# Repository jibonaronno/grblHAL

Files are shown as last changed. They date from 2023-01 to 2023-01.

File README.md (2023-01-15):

# grblHAL
STM32F401 GRBL Controller over BlackPill board.

Schematic and layout are completed. Screw Terminal Connectors and optos are aligned. Added 4 TMC2208.<br>

### Inspired from <a href="https://github.com/avizienis/Minimal-Black-Pill--STM32F4xx-BOB-for-grblHAL">Minimal-Black-Pill--STM32F4xx-BOB-for-grblHAL</a><br>
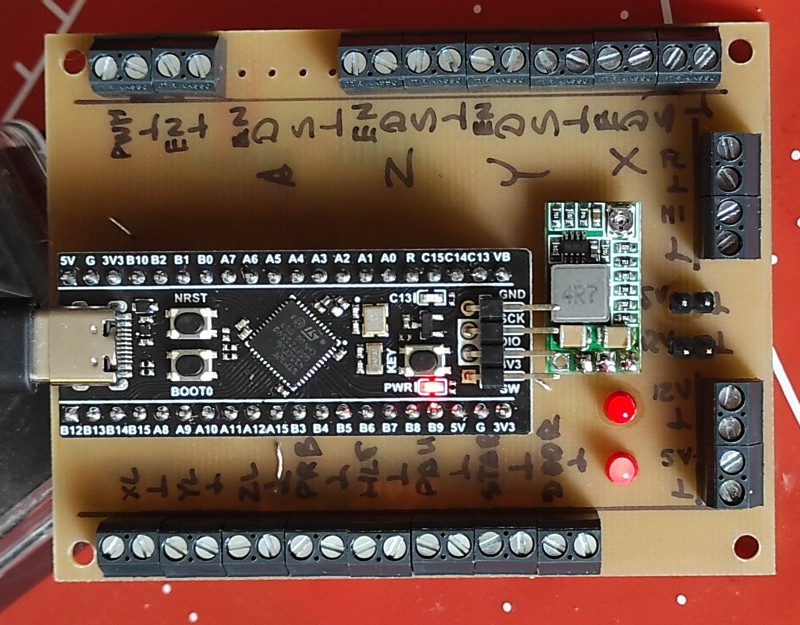
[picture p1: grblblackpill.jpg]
Image Not Found
<br>

### Our Kicad design below.<br/>
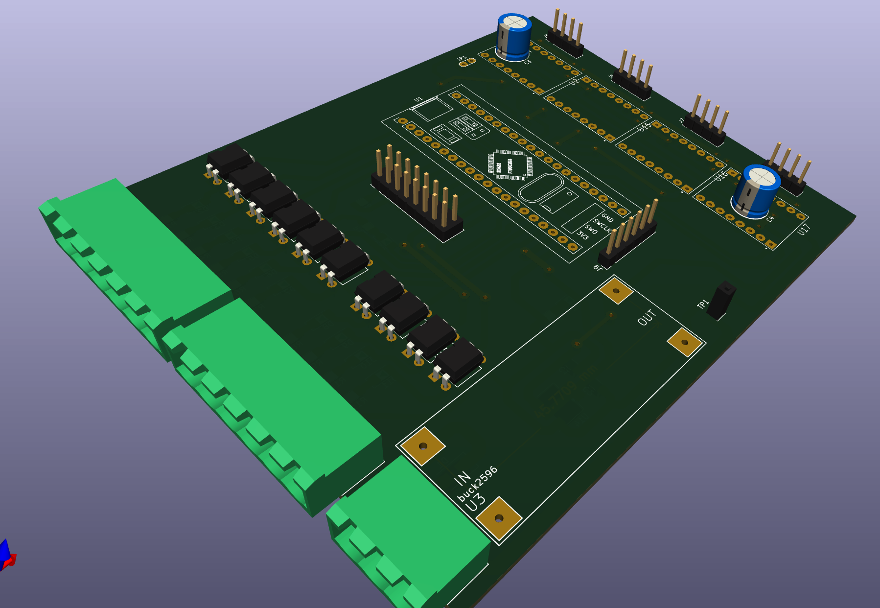
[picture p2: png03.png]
<br>
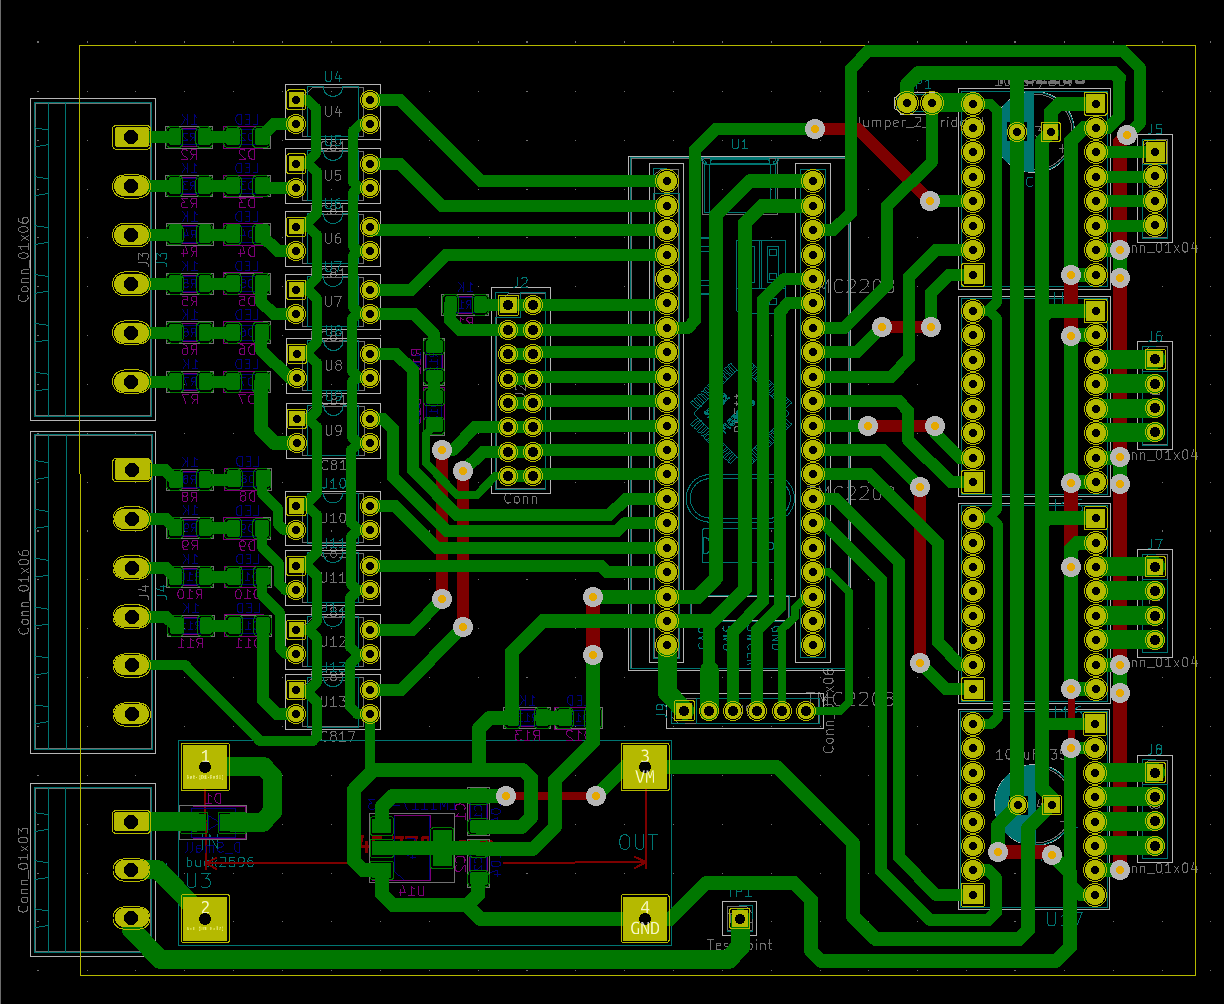
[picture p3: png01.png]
<br>
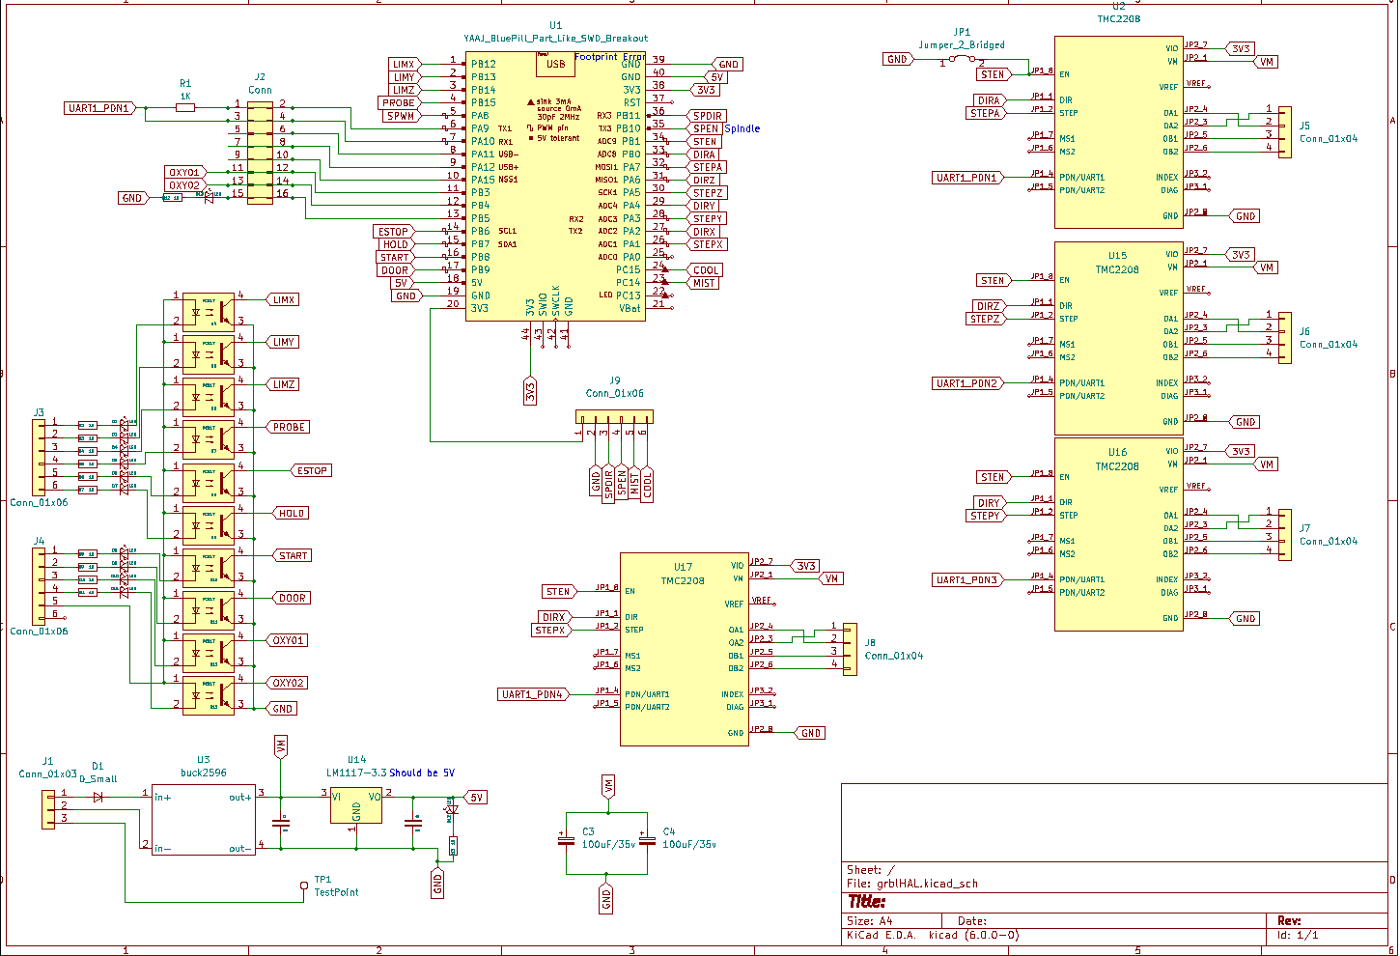
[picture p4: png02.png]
<br>

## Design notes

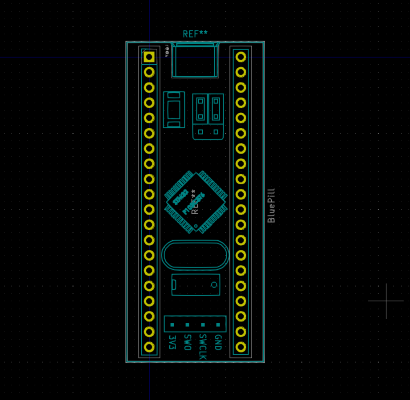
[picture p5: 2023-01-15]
images/YAAJ_BluePill_1_Footprint.png

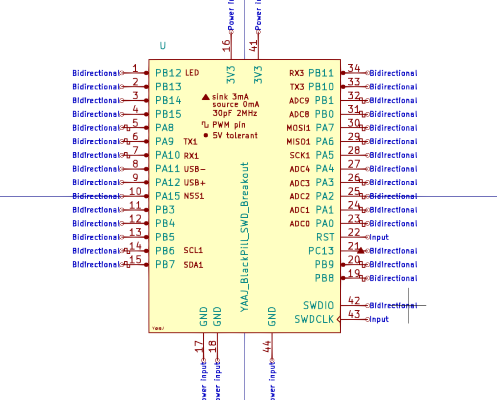
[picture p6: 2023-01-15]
images/YAAJ_BlackPill_SWD_Breakout_Sym.png

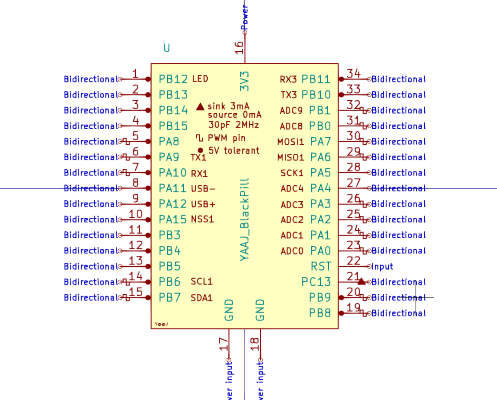
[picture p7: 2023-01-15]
images/YAAJ_BlackPill_Sym.png

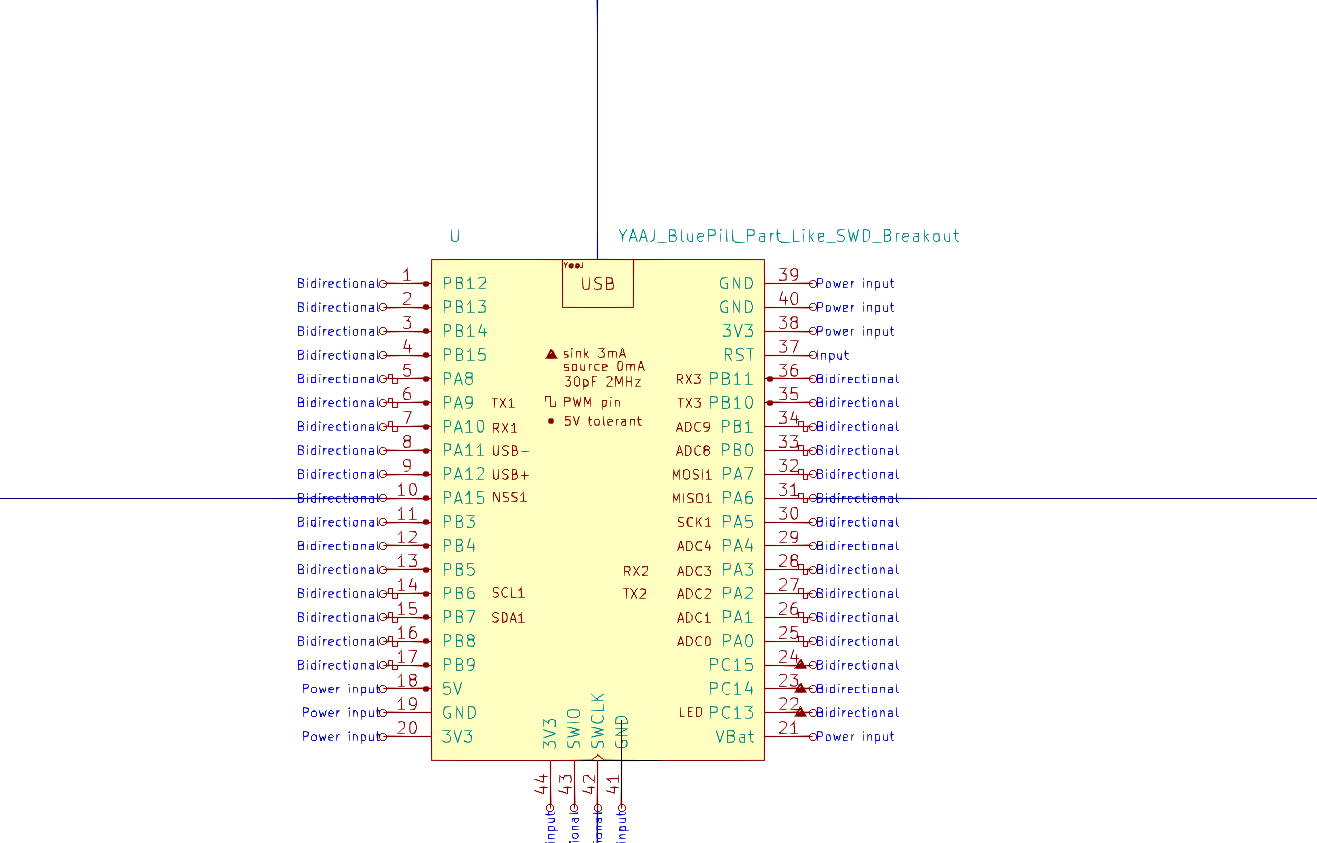
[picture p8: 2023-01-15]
images/YAAJ_BluePill_Part_Like_SWD_Breakout.png

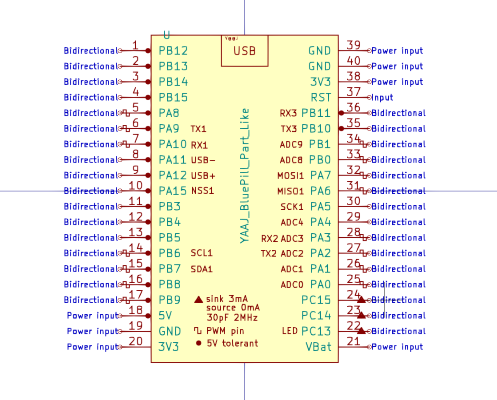
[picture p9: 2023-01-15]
images/YAAJ_BluePill_Part_Like_Sym.png

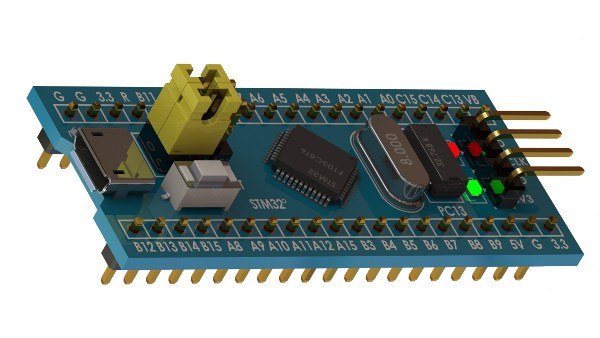
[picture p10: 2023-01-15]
images/BluePill.JPG

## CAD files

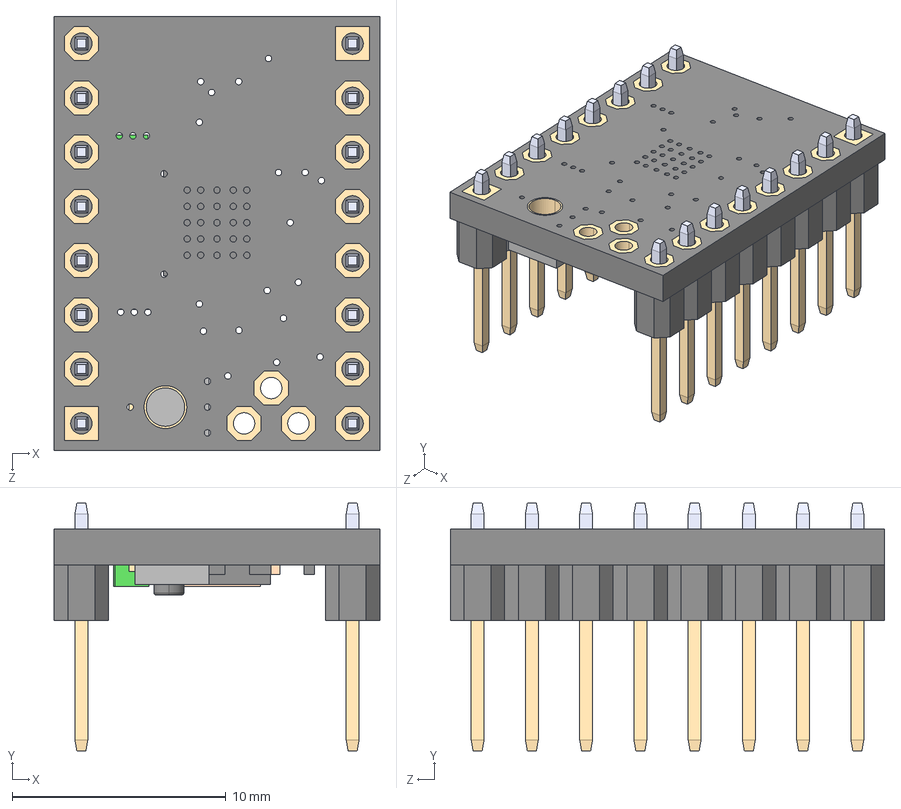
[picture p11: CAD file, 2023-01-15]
TMC2208_SILENTSTEPSTICK/TMC2208_SILENTSTEPSTICK.step
15.2 x 11.6 x 20.3 mm

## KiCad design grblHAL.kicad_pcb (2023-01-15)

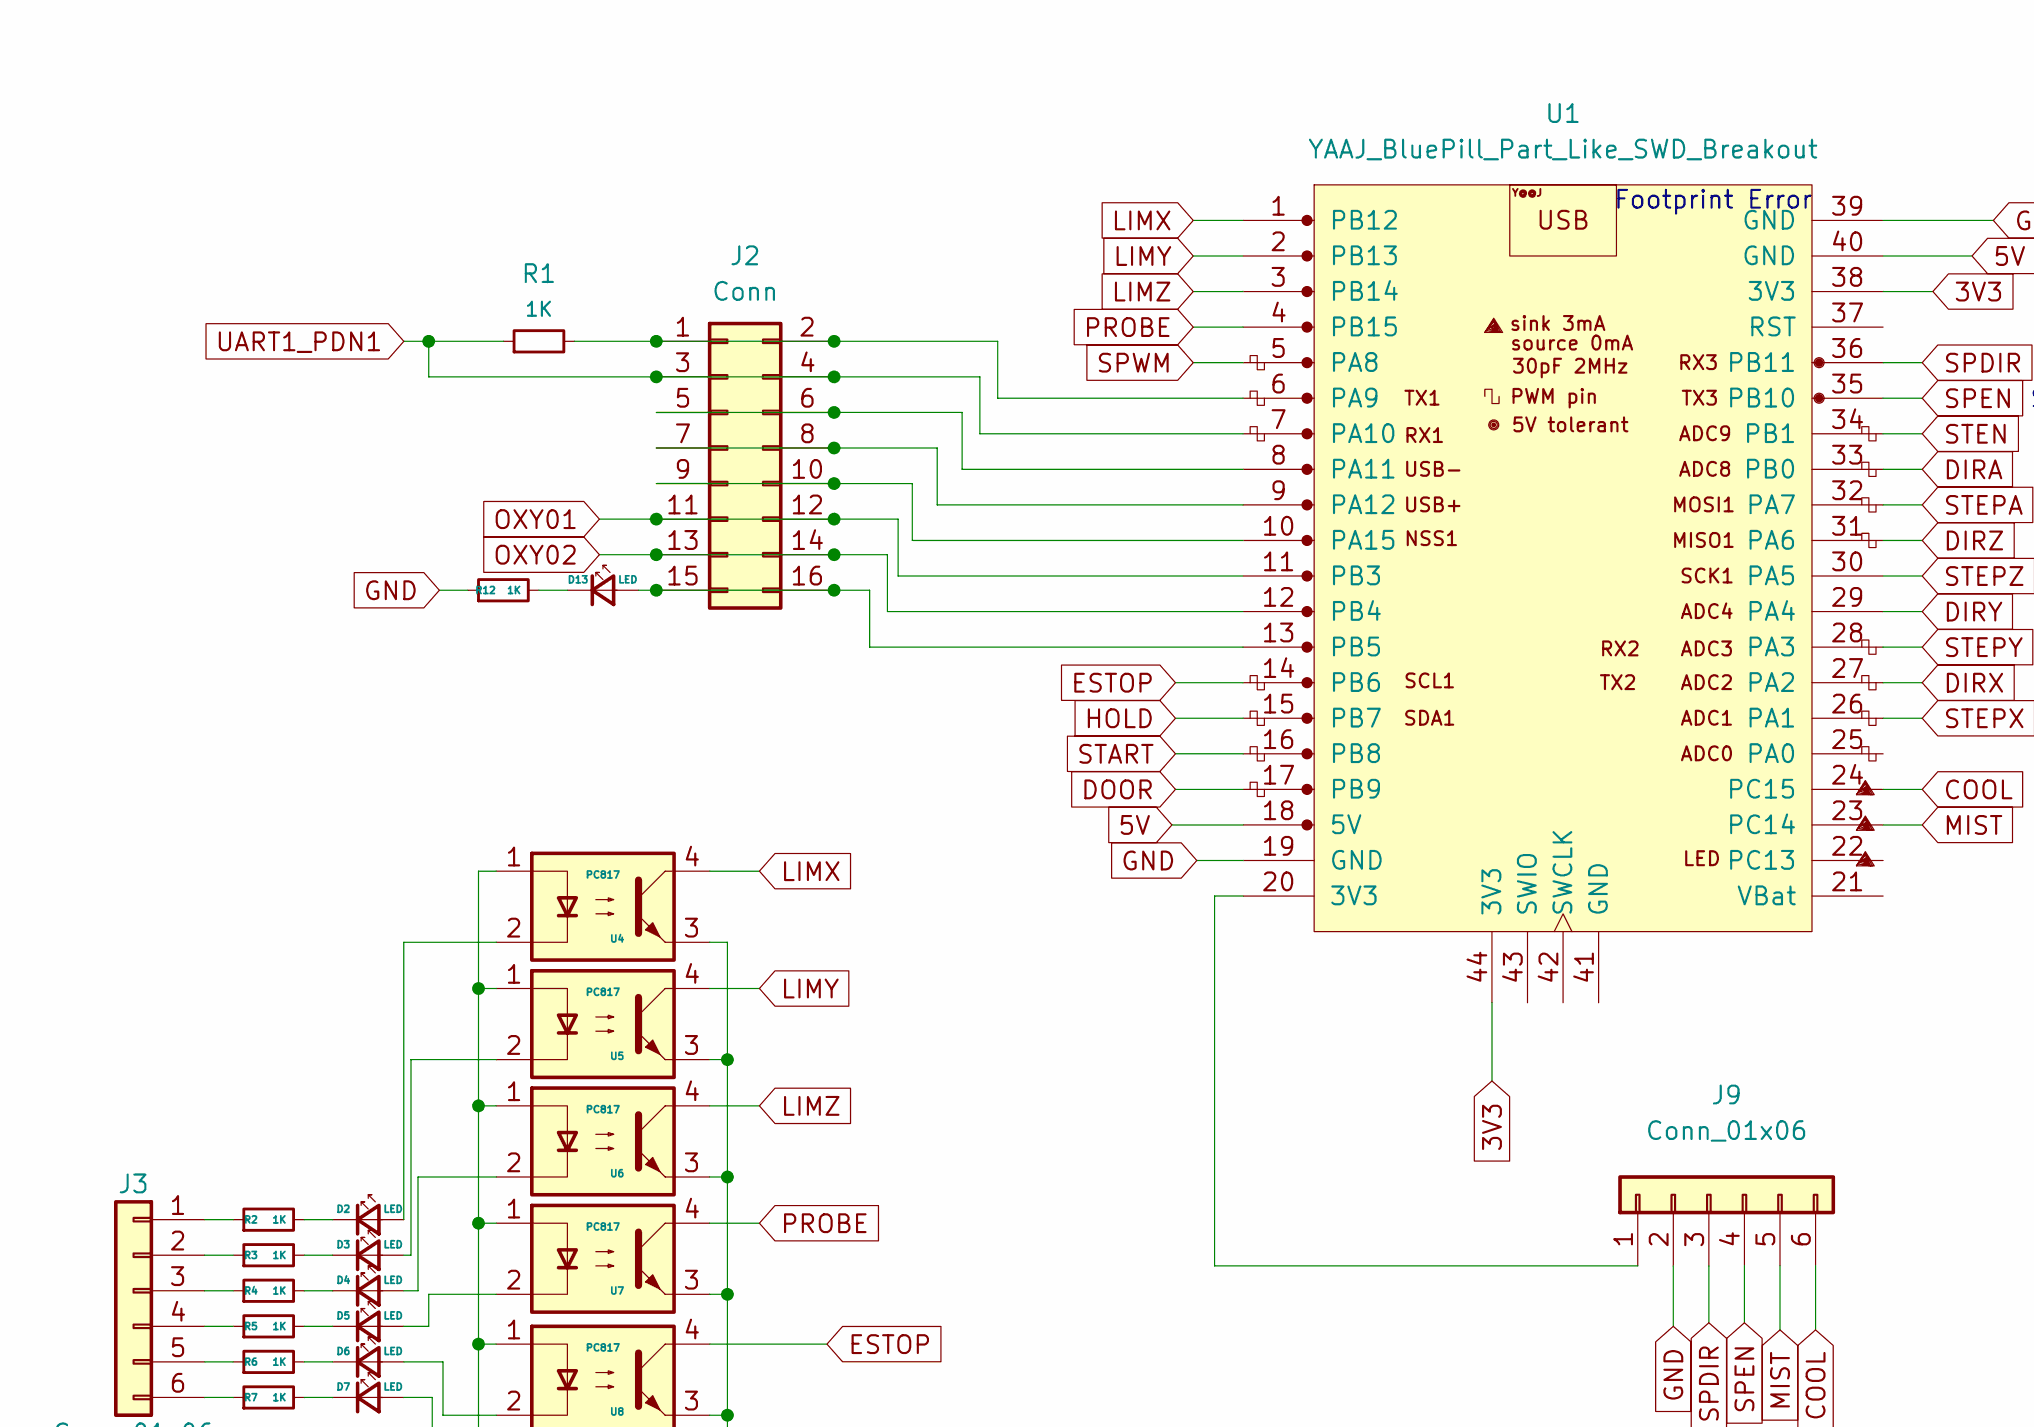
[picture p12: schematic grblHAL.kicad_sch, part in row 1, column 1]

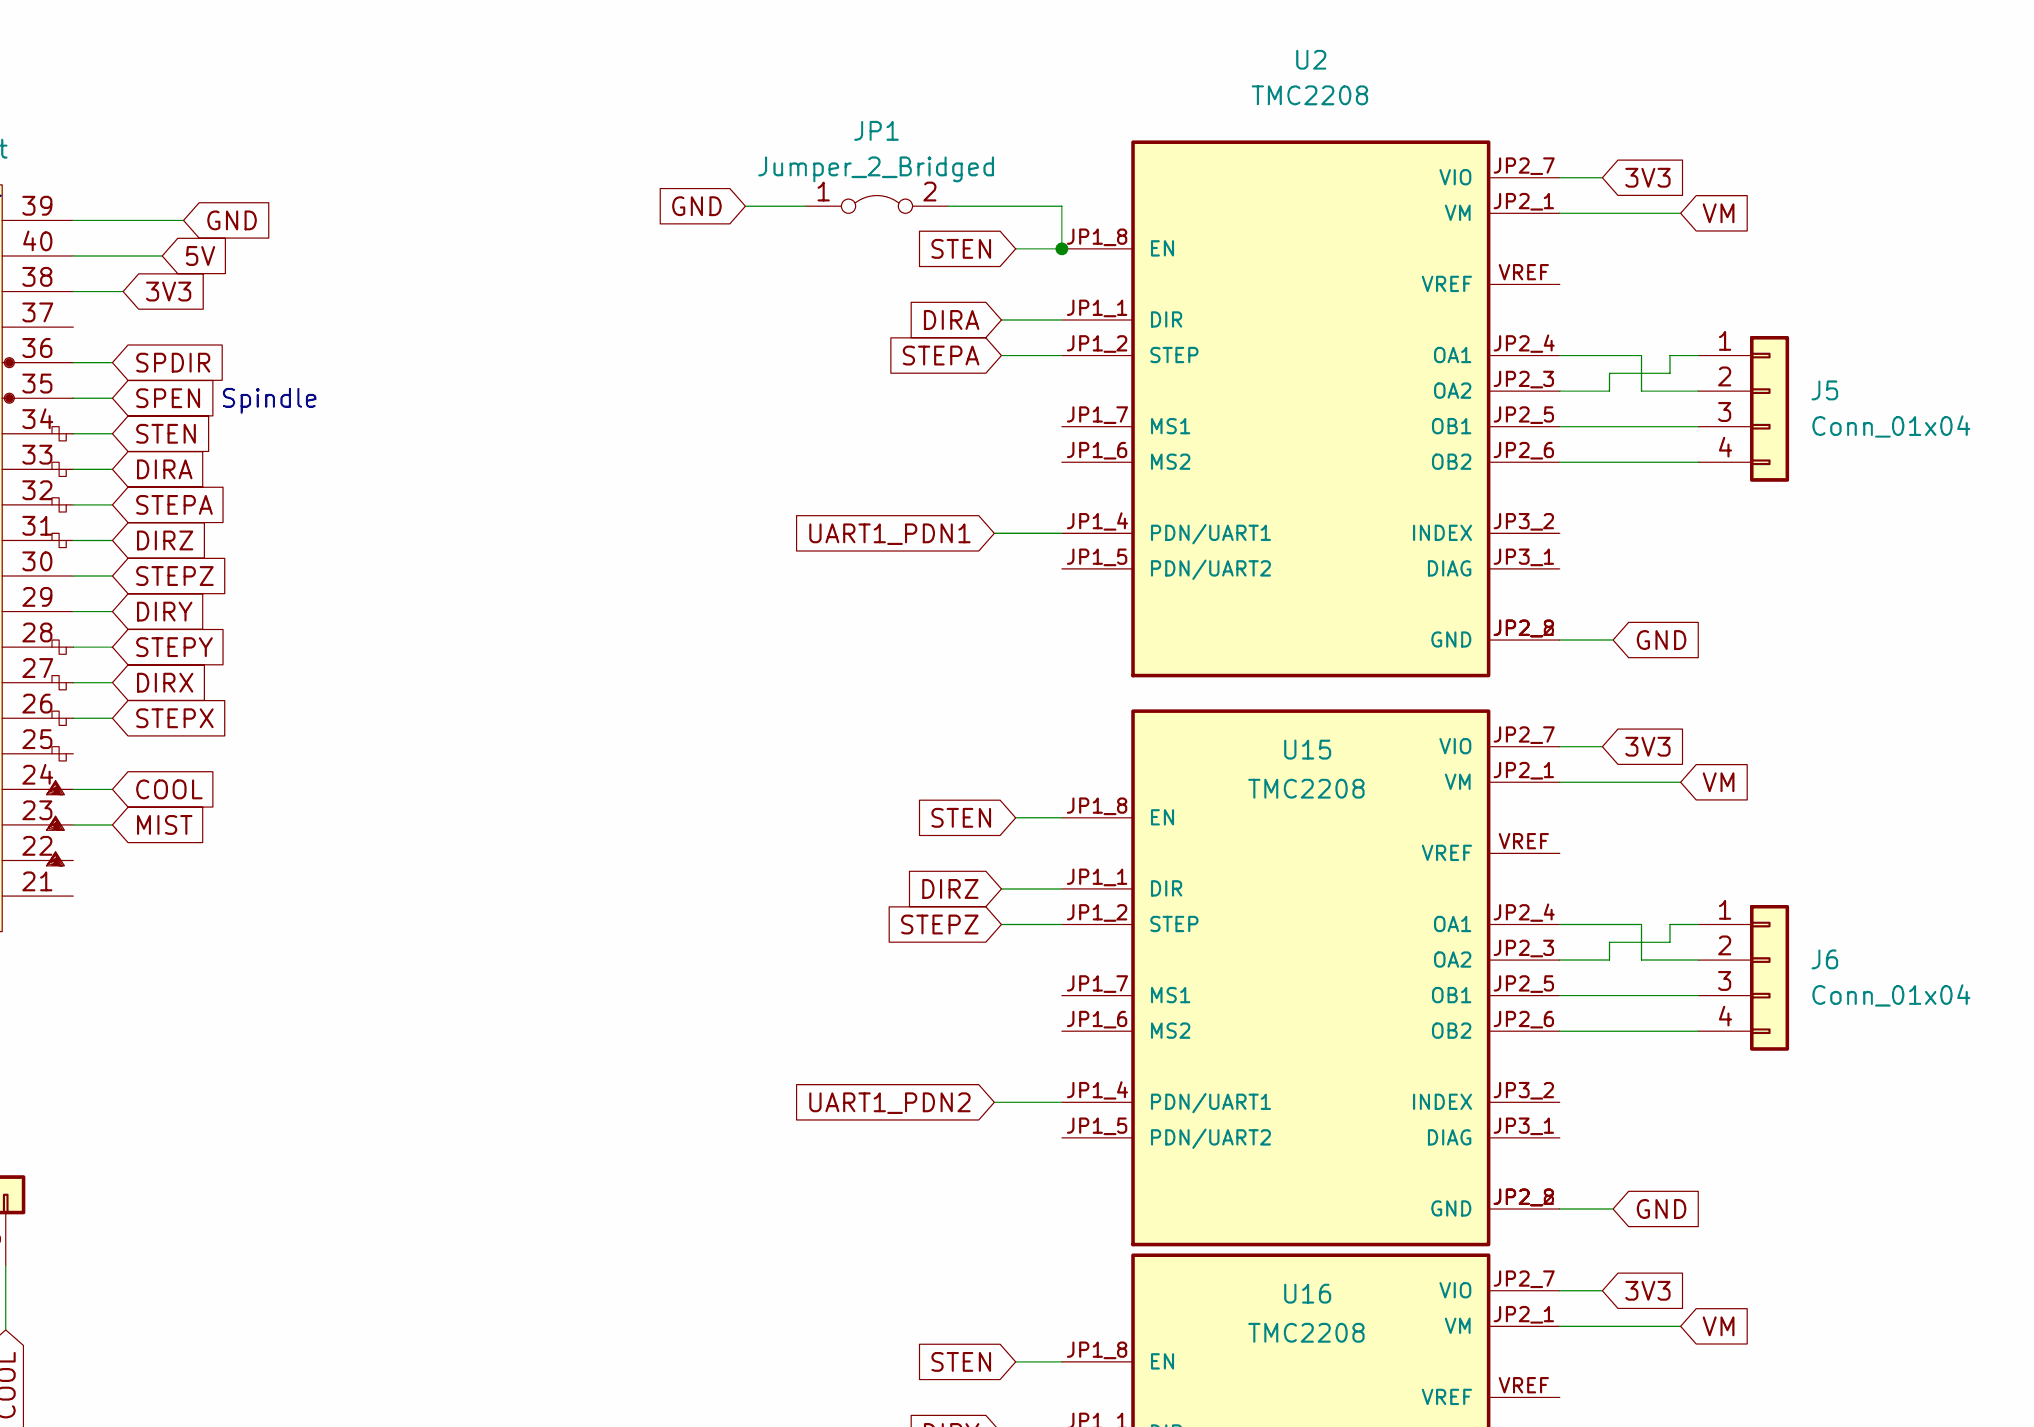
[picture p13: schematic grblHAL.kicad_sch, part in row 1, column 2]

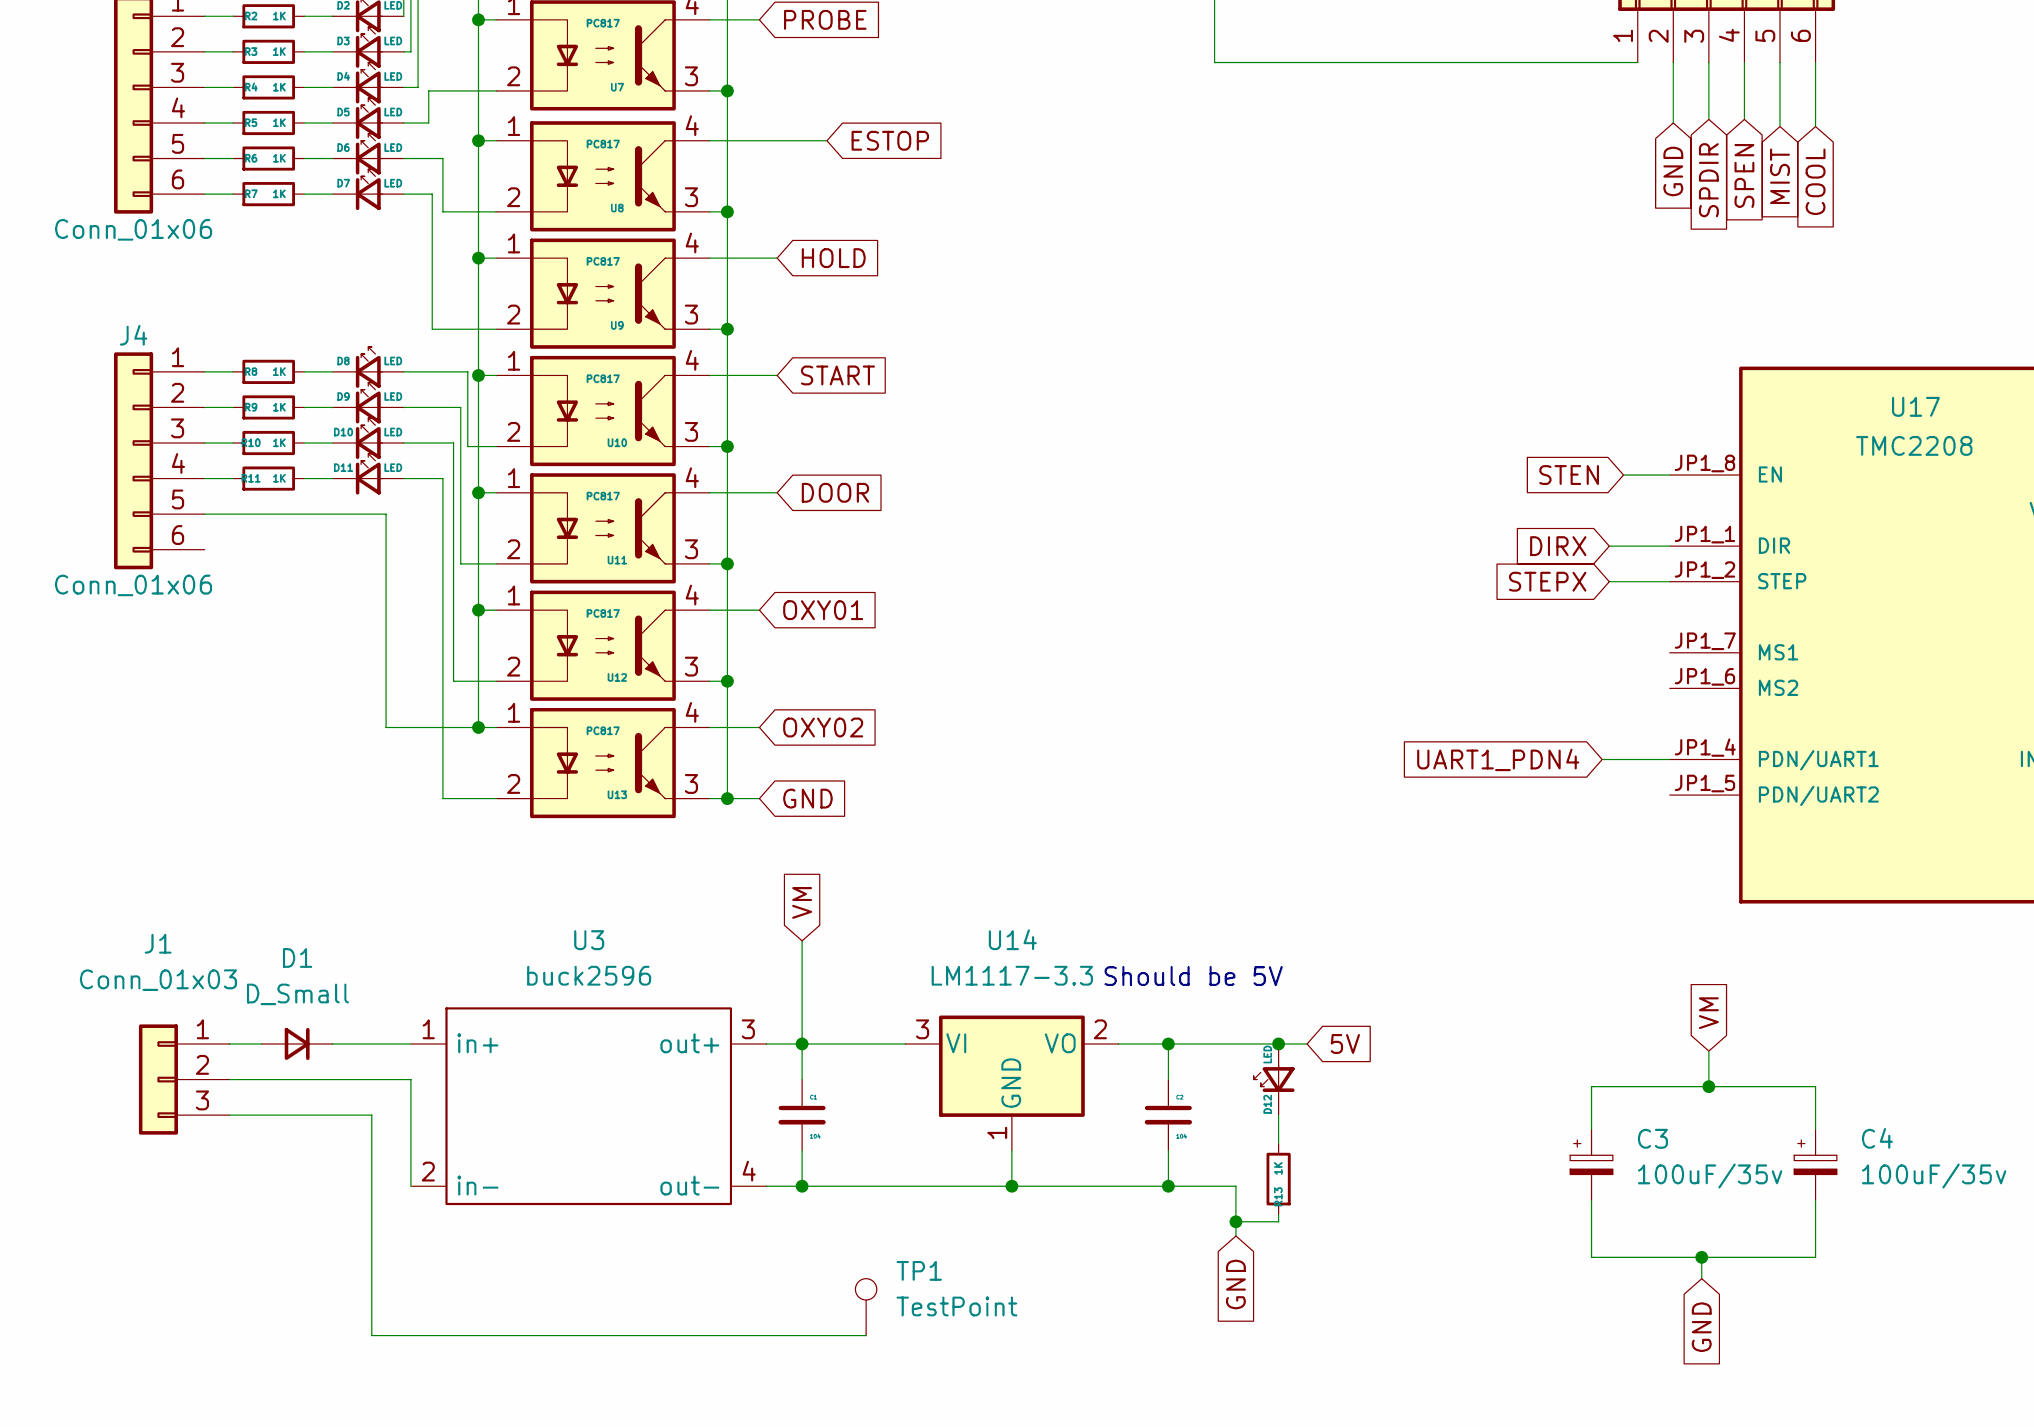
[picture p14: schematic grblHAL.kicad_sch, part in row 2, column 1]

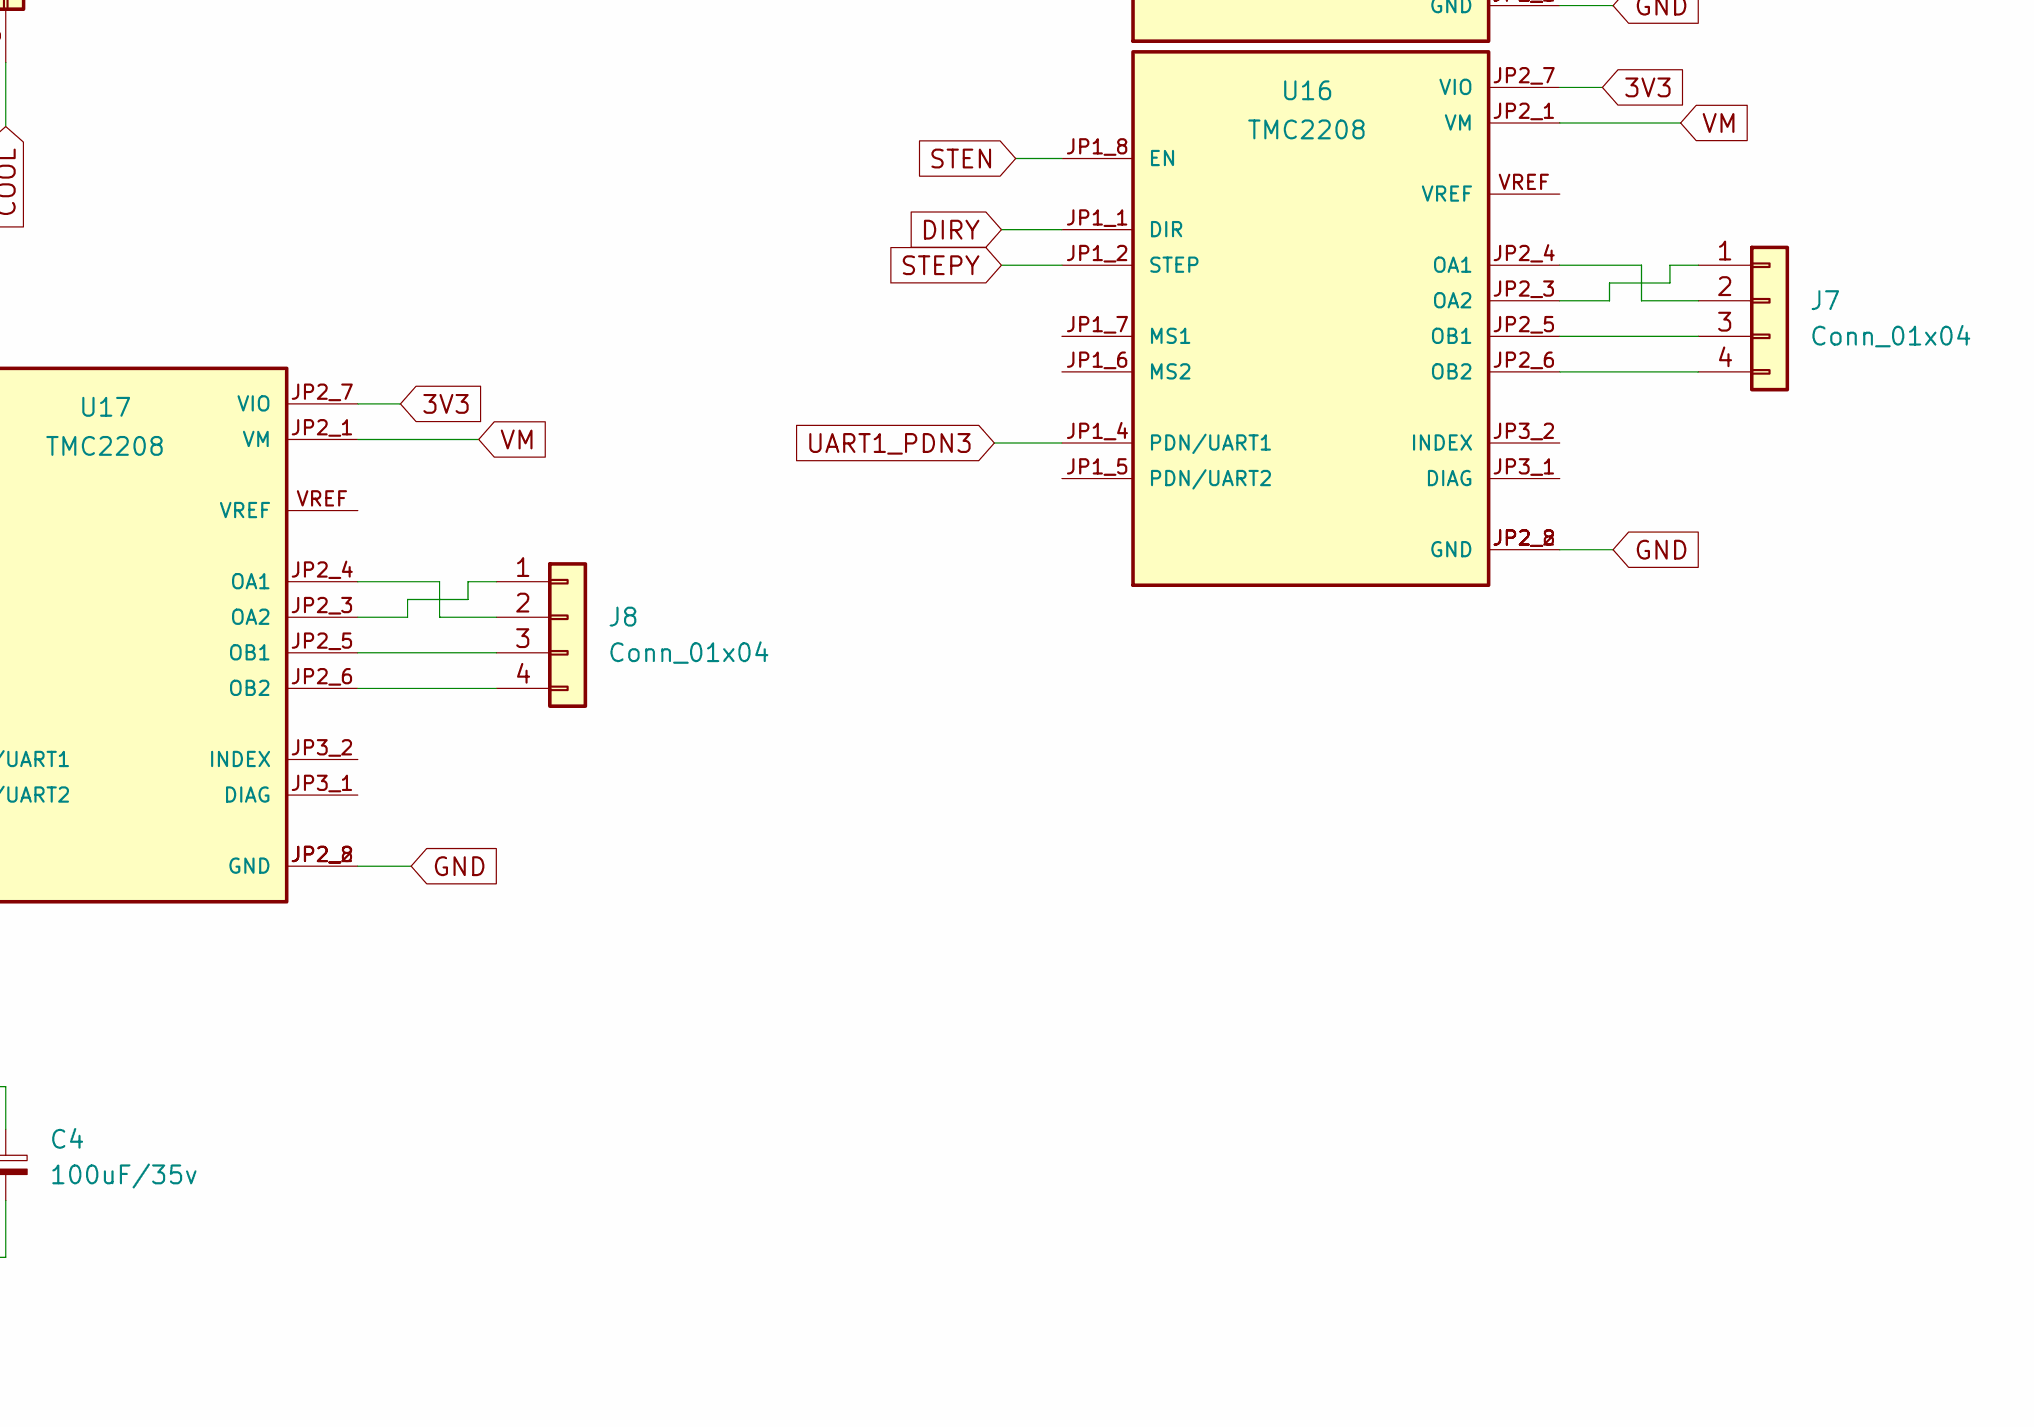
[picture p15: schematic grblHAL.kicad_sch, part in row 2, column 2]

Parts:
C1, C2: 104; C_1206_3216Metric_Pad1.33x1.80mm_HandSolder
C3, C4: 100uF/35v; CP_Radial_D8.0mm_P3.50mm
D1: D_Small; D_SMA
D2, D3, D4, D5, D6, D7, D8, D9, D10, D11, D12, D13: LED; LED_1206_3216Metric_Pad1.42x1.75mm_HandSolder
J1: Conn_01x03; PhoenixContact_MSTBA_2,5_3-G_1x03_P5.00mm_Horizontal
J2: Conn; PinHeader_2x08_P2.54mm_Vertical
J3, J4: Conn_01x06; PhoenixContact_MSTBA_2,5_6-G-5,08_1x06_P5.08mm_Horizontal
J5, J6, J7, J8: Conn_01x04; PinHeader_1x04_P2.54mm_Vertical
J9: Conn_01x06; PinHeader_1x06_P2.54mm_Vertical
JP1: Jumper_2_Bridged; TestPoint_2Pads_Pitch2.54mm_Drill0.8mm
R1, R2, R3, R4, R5, R6, R7, R8, R9, R10, R11, R12, R13: 1K; R_1206_3216Metric_Pad1.30x1.75mm_HandSolder
TP1: TestPoint; PinSocket_1x01_P2.54mm_Vertical
U1: YAAJ_BluePill_Part_Like_SWD_Breakout; YAAJ_BluePill_SWD_1
U2, U15, U16, U17: TMC2208; MODULE_TMC2208_SILENTSTEPSTICK
U3: buck2596; DC_DC_LM2596_small
U4, U5, U6, U7, U8, U9, U10, U11, U12, U13: PC817; DIP-4_W7.62mm
U14: LM1117-3.3; SOT-223-3_TabPin2

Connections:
3V3: U1.38 (3V3), U1.44 (3V3), U2.JP2_7 (VIO), U15.JP2_7 (VIO), U16.JP2_7 (VIO), U17.JP2_7 (VIO)
5V: C2.1, D12.2 (A), U1.18 (5V), U1.40 (GND), U14.2 (VO)
COOL: J9.6, U1.24 (PC15)
DIRA: U1.33 (PB0), U2.JP1_1 (DIR)
DIRX: U1.27 (PA2), U17.JP1_1 (DIR)
DIRY: U1.29 (PA4), U16.JP1_1 (DIR)
DIRZ: U1.31 (PA6), U15.JP1_1 (DIR)
DOOR: U1.17 (PB9), U11.4
ESTOP: U1.14 (PB6), U8.4
GND: C1.2, C2.2, C3.2, C4.2, J9.2, JP1.1 (A), R12.1, R13.1, U1.19 (GND), U1.39 (GND), U2.JP2_2 (GND), U2.JP2_8 (GND), U3.4 (out-), U4.3, U5.3, U6.3, U7.3, U8.3, U9.3, U10.3, U11.3, U12.3, U13.3, U14.1 (GND), U15.JP2_2 (GND), U15.JP2_8 (GND), U16.JP2_2 (GND), U16.JP2_8 (GND), U17.JP2_2 (GND), U17.JP2_8 (GND)
HOLD: U1.15 (PB7), U9.4
LIMX: U1.1 (PB12), U4.4
LIMY: U1.2 (PB13), U5.4
LIMZ: U1.3 (PB14), U6.4
MIST: J9.5, U1.23 (PC14)
unnamed: D1.1 (K), U3.1 (in+)
unnamed: D1.2 (A), J1.1
unnamed: D2.1 (K), R2.2
unnamed: D2.2 (A), U4.2
unnamed: D3.1 (K), R3.2
unnamed: D3.2 (A), U5.2
unnamed: D4.1 (K), R4.2
unnamed: D4.2 (A), U6.2
unnamed: D5.1 (K), R5.2
unnamed: D5.2 (A), U7.2
unnamed: D6.1 (K), R6.2
unnamed: D6.2 (A), U8.2
unnamed: D7.1 (K), R7.2
unnamed: D7.2 (A), U9.2
unnamed: D8.1 (K), R8.2
unnamed: D8.2 (A), U10.2
unnamed: D9.1 (K), R9.2
unnamed: D9.2 (A), U11.2
unnamed: D10.1 (K), R10.2
unnamed: D10.2 (A), U12.2
unnamed: D11.1 (K), R11.2
unnamed: D11.2 (A), U13.2
unnamed: D12.1 (K), R13.2
unnamed: D13.1 (K), R12.2
unnamed: D13.2 (A), J2.15, J2.16, U1.13 (PB5)
unnamed: J1.2, U3.2 (in-)
unnamed: J1.3, TP1.1
unnamed: J2.1, J2.2, R1.2, U1.6 (PA9)
unnamed: J2.5, J2.6, U1.8 (PA11)
unnamed: J2.7, J2.8, U1.9 (PA12)
unnamed: J2.9, J2.10, U1.10 (PA15)
unnamed: J3.1, R2.1
unnamed: J3.2, R3.1
unnamed: J3.3, R4.1
unnamed: J3.4, R5.1
unnamed: J3.5, R6.1
unnamed: J3.6, R7.1
unnamed: J4.1, R8.1
unnamed: J4.2, R9.1
unnamed: J4.3, R10.1
unnamed: J4.4, R11.1
unnamed: J4.5, U4.1, U5.1, U6.1, U7.1, U8.1, U9.1, U10.1, U11.1, U12.1, U13.1
unnamed: J5.1, U2.JP2_3 (OA2)
unnamed: J5.2, U2.JP2_4 (OA1)
unnamed: J5.3, U2.JP2_5 (OB1)
unnamed: J5.4, U2.JP2_6 (OB2)
unnamed: J6.1, U15.JP2_3 (OA2)
unnamed: J6.2, U15.JP2_4 (OA1)
unnamed: J6.3, U15.JP2_5 (OB1)
unnamed: J6.4, U15.JP2_6 (OB2)
unnamed: J7.1, U16.JP2_3 (OA2)
unnamed: J7.2, U16.JP2_4 (OA1)
unnamed: J7.3, U16.JP2_5 (OB1)
unnamed: J7.4, U16.JP2_6 (OB2)
unnamed: J8.1, U17.JP2_3 (OA2)
unnamed: J8.2, U17.JP2_4 (OA1)
unnamed: J8.3, U17.JP2_5 (OB1)
unnamed: J8.4, U17.JP2_6 (OB2)
unnamed: J9.1, U1.20 (3V3)
OXY01: J2.11, J2.12, U1.11 (PB3), U12.4
OXY02: J2.13, J2.14, U1.12 (PB4), U13.4
PROBE: U1.4 (PB15), U7.4
SPDIR: J9.3, U1.36 (PB11)
SPEN: J9.4, U1.35 (PB10)
SPWM: U1.5 (PA8)
START: U1.16 (PB8), U10.4
STEN: JP1.2 (B), U1.34 (PB1), U2.JP1_8 (EN), U15.JP1_8 (EN), U16.JP1_8 (EN), U17.JP1_8 (EN)
STEPA: U1.32 (PA7), U2.JP1_2 (STEP)
STEPX: U1.26 (PA1), U17.JP1_2 (STEP)
STEPY: U1.28 (PA3), U16.JP1_2 (STEP)
STEPZ: U1.30 (PA5), U15.JP1_2 (STEP)
UART1_PDN1: J2.3, J2.4, R1.1, U1.7 (PA10), U2.JP1_4 (PDN/UART1)
UART1_PDN2: U15.JP1_4 (PDN/UART1)
UART1_PDN3: U16.JP1_4 (PDN/UART1)
UART1_PDN4: U17.JP1_4 (PDN/UART1)
VM: C1.1, C3.1, C4.1, U2.JP2_1 (VM), U3.3 (out+), U14.3 (VI), U15.JP2_1 (VM), U16.JP2_1 (VM), U17.JP2_1 (VM)

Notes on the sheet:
Spindle
Footprint Error
Should be 5V

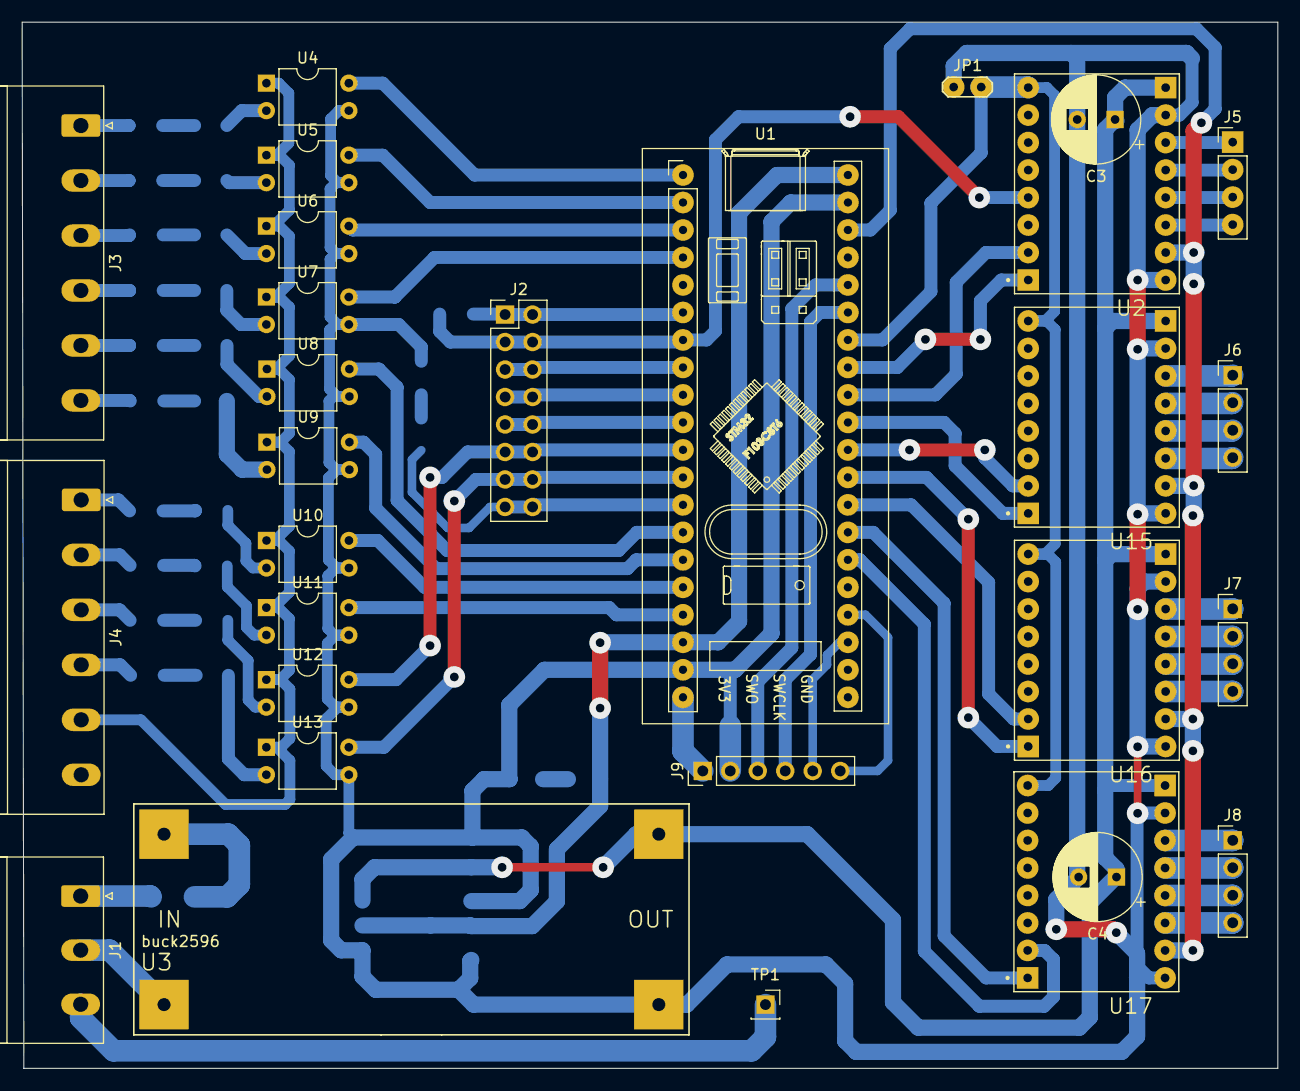
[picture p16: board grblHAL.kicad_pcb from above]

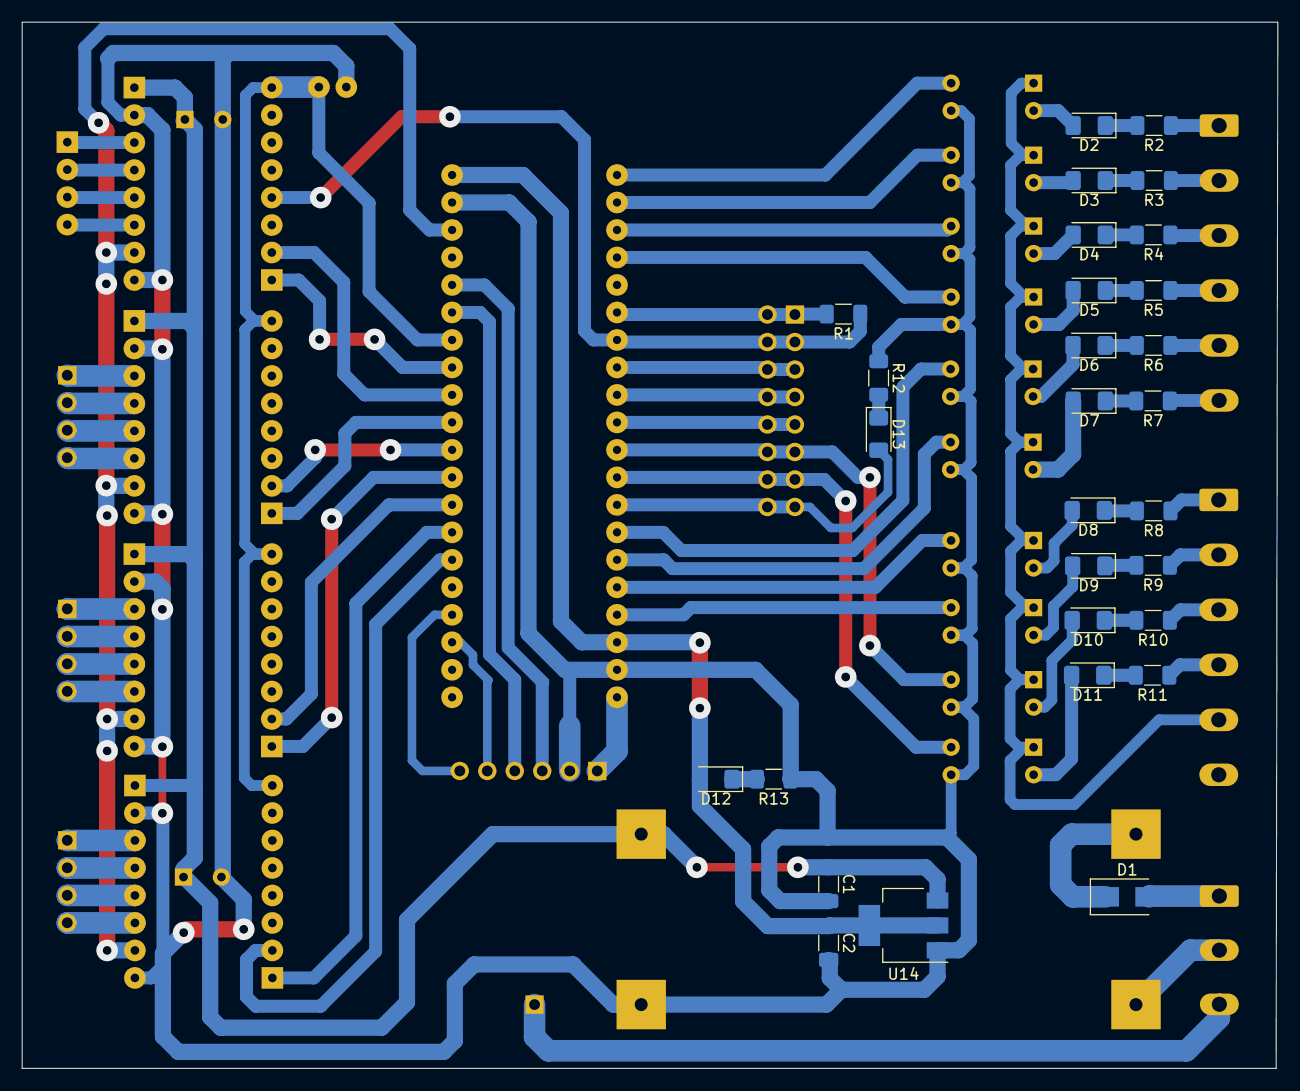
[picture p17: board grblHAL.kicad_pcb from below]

Board: 2 copper layers, 116.0 x 96.7 mm, 58 parts (29 on the bottom side), 87 nets.

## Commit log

2023-01-15 Nets Opto 1 TMC
    [TMC2208_SILENTSTEPSTICK.step, grblHAL.kicad_pcb, grblHAL.kicad_sch]
2023-01-15 Schematic Layout Nets Opto 1 TMC Stage 1
2023-01-15 Schematic Layout Nets Opto 4 TMC Stage 2
    [grblHAL.kicad_pcb, grblHAL.kicad_sch]
2023-01-15 Schematic Full Layout Nets Opto Connector 4-TMC Stage 3
    [grblHAL.kicad_pcb, grblHAL.kicad_sch]
